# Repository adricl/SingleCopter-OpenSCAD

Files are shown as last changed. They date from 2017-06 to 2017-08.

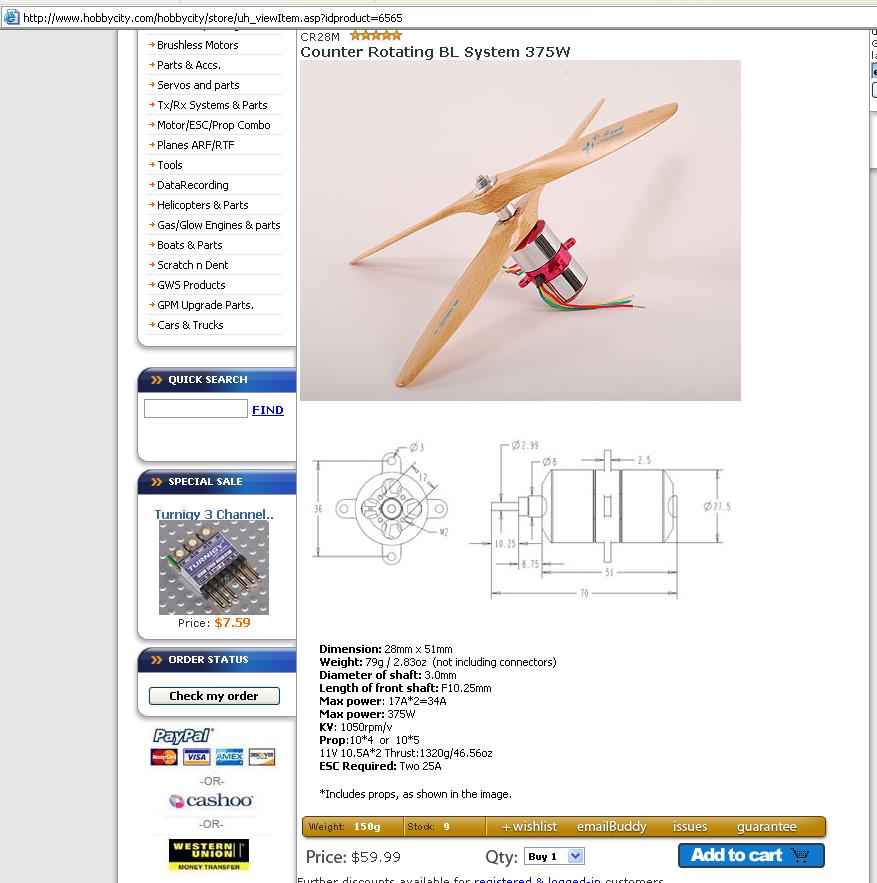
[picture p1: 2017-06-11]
Counter Rotating BL System 375W.JPG

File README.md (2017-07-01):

# SingleCopter-OpenSCAD
Single Copter OpenSCAD Design

### BOM
- 4x GridFins
- 1x Outside Frame and Central Mount
- 2x Carbon Fibre rods
- 1x Contra Rotaing Motor i.e. https://hobbyking.com/en_us/contra-rotating-bl-system-375w.html?___store=en_us
- 2x 20amp esc
- 2x Blades for motor 10" x 04" or 10" x 05"
- 1x 3 cell battery
- 1x Flight Controller Ardupilot (pixRacer) gps if needed
- 4x Servos i.e. https://hobbyking.com/en_us/turnigytm-tgy-d56mg-coreless-ds-mg-hv-servo-1-2kg-0-10sec-5-6g.html?___store=en_us 
- 1x pdb to supply servos depends on servo voltage. 
- 1x battery 

### SETUP
https://github.com/mirkix/BBBMINI/blob/master/doc/software/software.md
http://ardupilot.org/copter/docs/singlecopter-and-coaxcopter.html

Impliment this for debugging https://github.com/dogmaphobic/mavesp8266

TODO:
BBBMini Setup:

Get Servo Range
SERVO1_MIN: the forward flap/servo’s lowest PWM value before it hits its physical limits.
SERVO1_MAX: the forward flap/servo’s highest PWM value before it hits its physical limits.
SERVO1_TRIM: the forward flap/servo’s PWM value close to what is required to keep the vehicle from spinning.
SERVO1_REVERSED: the forward flap/servo’s reverse setting. 0 = servo moves in default direction, 1 to reverse direction of movement.

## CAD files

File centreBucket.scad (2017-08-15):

// Motor mount for centre of bucket dual copter.
use <library/Utils.scad>
use <gridFins.scad>
$fn=50;

//Rods
rodSize = 12 + 1; //1 more than the actual for 3d printer tolerances 
rodLength = 280;
rodSeperatorWidth = 2;
rodGroupHeight = rodSize * 2 + rodSeperatorWidth;

//Motor Mount
motorMountWidthFromHole = 1;
motorMountHoleSize = 3 + 1; //1 more than the actual for 3d printer tolerances 
motorMountThickness = 2.5;
motorMountWidth = 7 + 1; //1 more than the actual for 3d printer tolerances 
motorMidHoleToHoleWidth = 36;
motorMountMinThickness = 31;

//Mount Screws
screwLength = 25;
nutWidth = 5 + 1; //1 more than the actual for 3d printer tolerances 
nutHeight= 2.5;

//Motor details
motorDepth = 30;
motorWidthInner = motorMidHoleToHoleWidth - motorMountHoleSize + motorMountWidthFromHole; // Mid mount hole to mid mount hole + rest of hole + 

mountInnerWidth = motorMountMinThickness;
mountWidth = motorMountWidthFromHole * 2 + motorMidHoleToHoleWidth + motorMountHoleSize; 

mountThickness = mountWidth - mountInnerWidth;
echo("Mount Width = ", mountThickness/2, " Inner Width=", mountInnerWidth, " OuterWidth ", mountWidth);
mountHeight = motorDepth + rodGroupHeight + motorMountThickness + 4;

//Bucket 
bucketDiameter = 255;
bucketThickness = 2;
bucketHeight = rodGroupHeight + 5;


//rods();
//bucket();
//gridFins();

//motorMount();

difference() {
	move(z=-4)centreMount();
	rods();
	gridFins();
}


module centreMount() {
	difference() {
		cylinder(h= mountHeight, d=mountWidth);
		move(z=-1) cylinder(h= mountHeight + 2, d=mountInnerWidth);
		motorMount();
		wireHole();
	}
}

module motorMount(){
	copy_move(rz=180) {
		copy_mirror(y=1) {
			move(rz=45) {
			//Mount for motor
			move(x=-motorMountWidth/2, y=mountInnerWidth/2 -1, z=mountHeight-motorMountThickness) 
			cube([motorMountWidth, mountThickness/2 +2,  motorMountThickness+1]);
			
			//Srew thread section
			move(x=0, y=mountInnerWidth/2 + motorMountHoleSize/2 + 1 , z=mountHeight - motorMountThickness - screwLength ) 
			cylinder(h=screwLength + 1, d=motorMountHoleSize);
			
			//Nut holder
			move(x=-nutWidth/2, y=mountInnerWidth/2 -1, z=mountHeight - motorMountThickness - screwLength + 2) 
			cube([nutWidth, mountThickness/2 +2,  motorMountThickness]);
			}
		}
	}
}

module wireHole(){
	wireHoleWidth = 5;
	copy_move(rz=90) {
			move(x=-motorMountWidth/2, y=mountInnerWidth/2 -1, z=mountHeight-motorMountThickness) 
			cube([wireHoleWidth, mountThickness/2 +2,  motorMountThickness+1]);
	}	
}

module gridFins(){
	copy_move(rz=90){
		copy_mirror(x=1){
			move(y=-20, x=125, z=5, ry=180) gridFin();
		}
	}
}

module bucket(){
	difference() {
		cylinder(h=bucketHeight, d= bucketDiameter + bucketThickness);
		move(z=-1) cylinder(h=bucketHeight+2, d= bucketDiameter);
	}
}

module rods(){
	rotate([0,0,45])
	copy_move(z=-rodSize - rodSeperatorWidth, rz=90) {
		move(x=-rodSize/2, y=-rodLength/2, z=rodGroupHeight/2) 
			cube([rodSize, rodLength, rodSize]);
		}
}

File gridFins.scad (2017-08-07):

use <library/Utils.scad>
use <MCAD/boxes.scad>
//Total Shape
height=15;
width=40;
length=100;

//Wall Thickness
thickness=1;

ductWidths = width - (thickness*4);
ductWidth=ductWidths/3;

ductHeightBottom = -1;
ductHeightTop = height + 2;

//M3
holeSize = 3;

//Front Corners
angle = 25;
subLength = length/3;
subWidth = width * (2/3);
$fn=50;

//servoScrewHole();

//move(rz=45) 
	gridFin();
//gridFinWithHole();
//servoMount();

module gridFin() {
		difference() {
			box();
			ductMiddle();
			mountHoles();
			sideDucts();
		}
		translate([ 0, thickness * 2 + ductWidth/2 + ductWidth ,5]) servoScrewHole();
		mountStrut();
}


module box(){
	
	difference() {
		translate([length/2, width/2, height/2]) 
			roundedBox([length, width, height], 2, false );

		subBoxes();
	}
}

module subBoxes() {
	subBox(0);
	translate([ 0, width, 0 ]) mirror([0,1,0]) subBox(0);
}

module subBox(ductWidth) {
	translate([length - sin(angle)*subLength, -cos(angle)*subWidth + ductWidth, -1]) 
	rotate(a=[0, 0, angle])  
	cube([ subLength +1, subWidth , ductHeightTop]);
}

module ductMiddle(){
		translate([thickness, ductWidth + thickness * 2 ,-1]) 
		cube([length - (2*thickness), ductWidth, ductHeightTop]);
}

module sideDucts(){
	sideDuct();
	translate([0, ductWidth * 3 + thickness * 4, 0]) 
		mirror([0,1,0])
		sideDuct();
}

module sideDuct(){
	ductLength = length - (2*thickness);
	
	difference() {
		translate([thickness, thickness, -1]) 
			cube([ductLength, ductWidth, ductHeightTop]);
		subBox(thickness);
	}
}

module mountHoles() {
	holeHeight = 5;
	translate([ -1, thickness + (ductWidth/2) ,holeHeight]) mountHole();
	translate([ -1, thickness * 2 + ductWidth/2 + ductWidth ,holeHeight]) rotate(a=90, v=[0,1,0]) cylinder(d=3.7, h=3.5);
	translate([ -1, thickness * 3 + ductWidth/2 + ductWidth * 2 ,holeHeight]) mountHole();
	
	translate([ length - thickness - 1, thickness * 2 + ductWidth/2 + ductWidth ,holeHeight]) mountHole();
	
	
}

module mountStrut() {
	holeHeight = 5;
	translate([ length - thickness - 1, thickness * 2 + ductWidth/2 + ductWidth ,holeHeight]) strut();
}

module strut() {
	subtractThickness= thickness +2;
	//echo(holeSize);
	rotate(a=90, v=[0,1,0]) cylinder(d=4, h=subtractThickness +20 );
}

module mountHole() {
	subtractThickness= thickness +2;
	echo(holeSize);
	rotate(a=90, v=[0,1,0]) cylinder(r=holeSize/2, h=subtractThickness );
}

module servoScrewHole () {
	screwWidth=2;
	servoMountHeight=2.5;
	servoWidth=3.7;
	thickness=3;	
	rotate(a=90, v=[0,1,0])
		difference() {
			cylinder(d = servoWidth+thickness, h=servoMountHeight+1);
			move(z=-1) cylinder(d=servoWidth, h=servoMountHeight+1);
			move(z=servoMountHeight - 1) cylinder(d=screwWidth, h=servoMountHeight+1);
		}
}

//module servoMount()
//{
//	longLength=28.78;
//	longWidth=3.8;
//	shortLength=16.85;
//	shortWidth=4.8;
//	midWidth=5.35;
//	height = 5;
//	
////	move(y=longLength/2) 
////	hull() {
////		move(x=shortWidth/2, y=shortWidth/2)
////			cylinder(d=shortWidth, h=height);
////		move(x=shortWidth/2 + shortLength - shortWidth, y=shortWidth/2 )
////			cylinder(d=shortWidth, h=height);
////	}
//
////move(x= shortLength/2 - longWidth/2)
////	copy_move(rz=180){
//		hull() {
//			move(x= longWidth/2, y= longWidth/2) 
//				cylinder(d= longWidth, h=height);
//			move(x= longWidth/2, y= longWidth/2 + longLength/2 - longWidth/2) 
//				cylinder(d= midWidth , h=height);
//		}
//		move() hull() {
//			move(x=longWidth/2, y= longWidth/2) 
//				cylinder(d= midWidth , h=height);
//			move(x= longWidth/2, y= longWidth/2 + longLength/2 - longWidth/2) 
//				cylinder(d= longWidth, h=height);
//			}
//}

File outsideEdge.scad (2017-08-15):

use <gridFins.scad>

propRadius = 101.6; //4 inches

outsideRadius = 3; 

height = 5;

centreD = 27.7;

rodLength= -propRadius - outsideRadius - 2;

$fn=50;
//comment out before rendering

//rods();

//servo(false);

//gridFins();

//Servo Mount test
//difference (){
//	outside_frame();
//	move(z=-20, y=-90, x=-150)cube([300,300,40]);
//}


////////////////////////////////

outside_frame();
//central_platform();




module outside_frame(){
	difference() {
		ousideRim();
		mountHoles();
		rods();
	}
}

module ousideRim(){
	difference() {
		union() {
			bottomRodMount();
			cylinder(h=height, r=propRadius + outsideRadius);
			difference(){
				move(z=-5)servoMounts();
				translate([0,0,5]) cylinder(h=3, r=propRadius + outsideRadius);
			}
		}
		translate([0,0,-17]) cylinder(h=height + 18, r=propRadius);
		move(z=-5) servoSubtracts();
		
		//Cleans up sides
		difference() {
			translate([0,0,-16]) cylinder(h=height + 20, r=propRadius + outsideRadius * 4);
			translate([0,0,-16]) cylinder(h=height + 20, r=propRadius + outsideRadius);
			
		}
	}
}

module central_platform(){
	difference(){
		cylinder(h=10, d=centreD, center=true);
		rods();
		mountHoles();
	}
}

module mountHoles(){
	//M3 Mount Holes
	
	zHeight=height/2 - 5; //WE moved the servos down 5
	angle=90;
	//Center Holes
	move( x= centreD/2  - 4,		z=zHeight , ry=angle) cylinder(h= height + 2, d=3 );
	move( x=-centreD/2 - 4, 		z=zHeight, ry=angle) cylinder(h= height + 2, d=3 );
	move( y= centreD/2  + 4,	z=zHeight, rx=angle) cylinder(h= height + 2, d=3 );
	move( y=-centreD/2 + 4, 	z=zHeight, rx=angle) cylinder(h= height + 2, d=3 );
	

	//Outside Holes
//	move(x=propRadius  - 4,	z=zHeight, ry=angle) cylinder(h= height + 2, d=3 );
//	move(x=-propRadius - 4, z=zHeight, ry=angle) cylinder(h= height + 2, d=3 );
//	move(y=propRadius  + 4,	z=zHeight, rx=angle) cylinder(h= height + 2, d=3 );
//	move(y=-propRadius + 4, z=zHeight, rx=angle) cylinder(h= height + 2, d=3 );
}

module bottomRodMount(){
	copy_mirror(x=-1, y=1){
		move(x=rodLength*sin(45), y=-rodLength*sin(45), ry=90, rz=-45) 
			cylinder(h= outsideRadius * 10 , d=9);
	}
}
module servoMounts (){
	copy_move(rz=270) {
		servoMount();
	}
}

module servoMount(){
	copy_mirror(y=1) {
		move(x=-35/2, y=-119, z=20, rx=270)
		move(z=16, x=35/2, y=35/2) resize(newsize=[34,19,4]) cylinder(h=4, d=35);
	}
}

module servoSubtracts (){
	copy_move(rz=270) {
		servoSubtract();
	}
}
module servoSubtract() {
	copy_mirror(y=1) {
		move(x=-35/2, y=-119, z=20, rx=270)
			move(z=0, x=(35 - 29.88)/2, y=(35 - 12)/2) servo(true);
	}
}

module servo(subtractHoles){
	move(x=(29.88-21.48)/2 ) //zero the servo
	difference() {	
		union() {
			move(z=20.1-3.5, x=-((29.88-21.48)/2), y=(12-9.45)/2,  ry=90) 
				cube([1.84,  9.45,  29.88]);
			cube([21.48, 12, 20.1 ]); //body
			if (subtractHoles) {
				move(x=-(29.88-21.48)/2 + 2, z=13, y=(12)/2)
					cylinder(h=10, d=2);
				move(x=21.48 + (29.88-21.48)/2 - 2, z=13, y=(12)/2)
					cylinder(h=10, d=2);
			}
		}
		
		if (!subtractHoles){
			move(x=-(29.88-21.48)/2 + 2, z=13, y=(12)/2)
				cylinder(h=4, d=2);
			move(x=21.48 + (29.88-21.48)/2 - 2, z=13, y=(12)/2)
				cylinder(h=4, d=2);
		}
	}
}	

module rods(){
	//3mm x 3mm
	rodWidthHeight=3;
	
	topZ = (height-rodWidthHeight)/2;
	bottomZ = topZ - rodWidthHeight - 2;
	echo(bottomZ);
	copy_move(z=bottomZ, rz=90){
		move(x=rodLength*sin(45) +2, y=rodLength*sin(45) , z=topZ, rz=45) 
			cube([propRadius * 2 + outsideRadius * 2 + 2 , rodWidthHeight, rodWidthHeight]);
	}
}

module gridFins(){
	copy_move(rz=90){
		copy_mirror(x=1){
			move(y=-20, x=96, z=7, ry=180) gridFin();
		}
	}
}

module copy_mirror(x=0,y=0,z=0) 
{ 
    children(); 
    mirror([x, y, z]) children(); 
} 

module copy_move(x=0,y=0,z=0,rx=0,ry=0,rz=0) { 
    children(); 
    move(x, y, z, rx, ry, rz) children(); 
} 

module move(x=0, y=0, z=0, rx=0, ry=0, rz=0) { 
	translate([x,y,z])rotate([rx,ry,rz]) children(); 
}

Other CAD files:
rodMounts.scad

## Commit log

2017-04-17 Added gridFin for ducts for single copter
    [gridFins.scad, gridFins.stl]
2017-04-17 Rounding the outside of the duct.
    [gridFins.scad]
2017-04-17 Adding this file was a mistake
    [gridFins.stl]
2017-04-18 Fixed Bug where moutnting holes are now removed
    [gridFins.scad]
2017-04-21 Added outside edge of single copter Need to add servo mounts and centre connectors
    [outsideEdge.scad]
2017-04-23 Added mouting for rods and centre motor mount
    [outsideEdge.scad]
2017-04-24 Added centre holes for mounting gridFins. Fixed issues with servo size.
    [outsideEdge.scad]
2017-04-25 Added outside servo mounts
    [outsideEdge.scad]
2017-04-25 Fixed the file for rendering
    [outsideEdge.scad]
2017-04-27 Resized gridfins to fit inside frame. Increased outside radius
    [gridFins.scad, outsideEdge.scad]
2017-05-12 Updated gridfins to have servo mount holes. Moved servo mount to line up with new holes.
    TODO remove the ouside edge where grid servo meets.
    [gridFins.scad, outsideEdge.scad]
2017-05-13 Updated Grid fins with servo hole mount and alligned the new grid fin holes in outside edge
    TODO: move servo mount to be 3d printable
    [outsideEdge.scad]
2017-05-14 Updated BOM
2017-05-16 Fixed hole size for servo mount
    [gridFins.scad]
2017-05-20 Moved Servo mounts down so we can print this TODO move holes to line up
    [gridFins.scad, outsideEdge.scad]
2017-05-20 Moved finn hieght down 5
    [outsideEdge.scad]
2017-05-20 Added test code for servo mounts
    [outsideEdge.scad]
2017-06-11 Adding centre peice for bucket copter
    [centreBucket.scad]
2017-06-11 Added screw mount holes
    [centreBucket.scad]
2017-06-11 Added image for motor details
2017-06-11 Fixed size error
    [centreBucket.scad]
2017-06-12 Corrections to dimentions after first 3d print
    [centreBucket.scad]
2017-06-12 Moved mount holes above the cross bar for placement of the gridfins
    [centreBucket.scad]
2017-06-13 Modified centralBucket with holes for wires and made bottom fatter
    [centreBucket.scad]
2017-06-18 Updated grid fins to fix new shape
    [centreBucket.scad, gridFins.scad]
2017-07-02 Updated grid fin to have hole for rotation
    [gridFins.scad]
2017-07-04 Created hole for the gridfin mount and moved it down to the bottom
    [centreBucket.scad, gridFins.scad]
2017-08-07 Thiner grid fin walls
    [gridFins.scad]
2017-08-15 added rodmounts for bucket
    [centreBucket.scad, outsideEdge.scad, rodMounts.scad]
